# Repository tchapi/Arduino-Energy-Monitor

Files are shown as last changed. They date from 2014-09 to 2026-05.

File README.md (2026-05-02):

Arduino and Node.js Energy Monitor
======================

Related blog post: https://tchap.me/blog/creating-a-simple-energy-monitor/

A little box that monitors the mains current and average room temperature and sends the data through WiFi to a server for storage, display and analysis.

Uses a **TMP36 temperature sensor** (like [this](https://www.sparkfun.com/products/10988)) and a **non-invasive current sensor** (like [this one](https://www.sparkfun.com/products/11005)), coupled with a **Wifi Shield** (this [one here](https://learn.adafruit.com/adafruit-cc3000-wifi)).

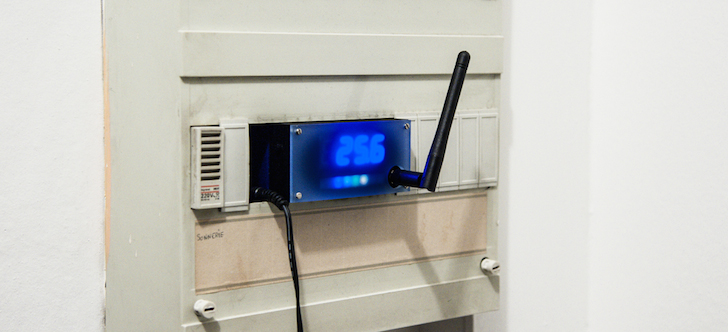
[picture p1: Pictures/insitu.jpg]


The box is the same size as a conventional NF EN 60898-1, and NFC 61-410 compliant circuit breaker, so it fits in your electrical panel.

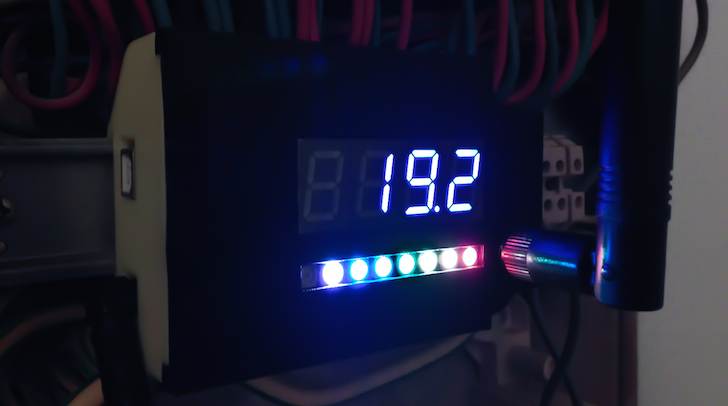
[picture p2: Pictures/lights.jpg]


## Code

The repo contains : 

  - the Arduino UNO code
  - A little Node.js server to receive the data

### Arduino code

The Arduino code is separated in different files, for ease of comprehension.

  - `CentralCurrentAndTempLogger.ino` is just here so the Arduino IDE is happy
  - `helpers.ino` define a general set of helper functions, like `readVcc()`
  - `display.ino` contains all the initialization processes for the 7-segment and the led strip
  - `wifi.ino` contains all the functions to work with WiFi
  - `current.ino` has all we need to compute current and temperature sensors
  - `main.ino` and `setup.ino` are self-explanatory.

> NB : these files are prefixed so that the compiler knows in which order to process them. This is required because in the Arduino IDE, there is no general file that imports every single file, so in order to define the compilation order, we need to rely on the filenames.

The configuration is stored in `config.h`. You need to copy `config.h.dist` to `config.h` and put your own settings (wifi, key) in there.

If you want to change the payload, you might want to look at lines `66`to `72` in `wifi.ino` :

```C
    client.print(encodedLength(str_temp) + encodedLength(str_power) + encodedLength(private_key) + 10);
    client.fastrprint(F("\r\n\r\nt="));
    urlEncode(client, str_temp, false, false);
    client.fastrprint(F("&w="));
    urlEncode(client, str_power, false, false);
    client.fastrprint(F("&key="));
    urlEncode(client, private_key, false, false);
```

> NB : it is advised to compile and upload the code with the Arduino IDE 1.0.5 version that can be found [here](http://www.arduino.cc/en/Main/OldSoftwareReleases#1.0.x) because the CC3000 shield is not really a big fan of the newer IDE releases.

### Server code

Of course, the server can be any application that can accept and process requests such as :

    POST 1.0 /data  key=123456789ABCD&w=346&t=23.5

The [Node.js](http://nodejs.org/) server provided is a very simple logger that stores the values in a file.

To launch the server, you first need to copy `config.json.dist` to `config.json` and put your own settings (log name, api path, key) in there.

Then, as for every standard Node.js app :

    node index.js

### About the `key` parameter

It's a very simple authentication system to prevent unwanted request to the server. Change for something only you know. The key must obviously be the same on the Arduino and on the server.

## Electronics

I created a custom PCB to hold the electronics (apart from the Arduino shield). It's designed on [Fritzing](http://fritzing.org/download/) which is a very practical tool.

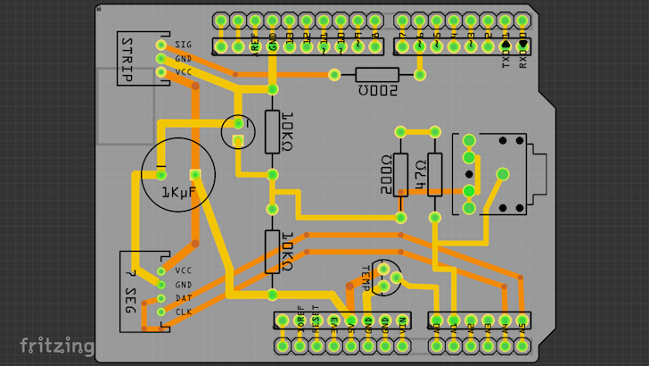
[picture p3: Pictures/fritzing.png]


The custom shield holds the connectors and some basic electronics. It is very simple to solder on your own.

BOM for the custom shield :

  - 1x 1000µF capacitor
  - 1x 10µF capacitor
  - 2x 10kΩ
  - 2x 200Ω
  - 1x 47Ω
  - 1x Stereo TRS connector (jack 3.5mm)
  - Some pin headers
  - 1x jst connector 3pin and x jst connector 4pin

To create the PCB, I use [Fritzing Fab](http://fab.fritzing.org/pricing) as well.

Other parts needed :

  - some wires
  - 1x Arduino UNO
  - 1x Adafruit CC3000 WiFi Shield
  - 1x antenna
  - 1x TMP36 temperature sensor
  - 1x non-invasive 30A current sensor
  - 1x Quad Alphanumeric Display - 0.54" Digits w/ I2C Backpack
  - 1x NeoPixel Stick - 8 x WS2812 5050 RGB LED with Integrated Drivers

## Casing

The casing consists of 3 _3D-printable_ parts :

  - the box in itself
  - the closing lid
  - the lid inset 

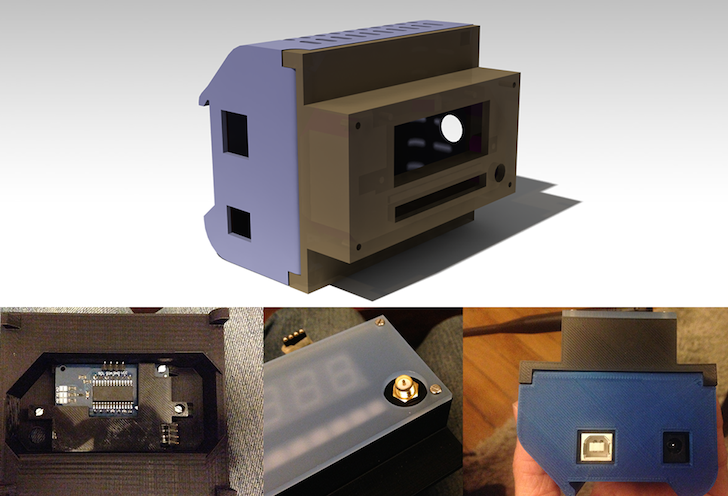
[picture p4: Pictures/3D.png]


All these parts are 3D printable on a regular **Rep Rap** or **Makerbot Replicator 2** for instance. The STL files (watertight, ready for print) are available in [the Design/Boîtier folder](https://github.com/tchapi/Arduino-Energy-Monitor/tree/master/Design/Bo%C3%AEtier%20principal/Exports%20STL).

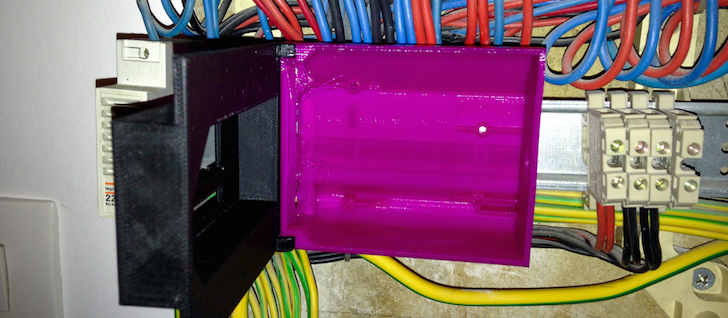
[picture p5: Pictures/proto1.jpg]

_A first prototype_

The CATIA files (.catpart and .catproduct) are available as well if you want to refactor them for your need.

To dim the displays and add a somehow nice touch to the objet, the fourth part is a little 3mm-thick plexiglass slap that can be cutted on a conventional laser cutter.

You can find the Illustrator file [here](https://github.com/tchapi/Arduino-Energy-Monitor/tree/master/Design/Bo%C3%AEtier%20principal/Plaque%20de%20protection%20plexiglas).

## Licence

Everything is released under the GNU GPL v2. Basically, you can reuse everything as long as you credit me somehow :)

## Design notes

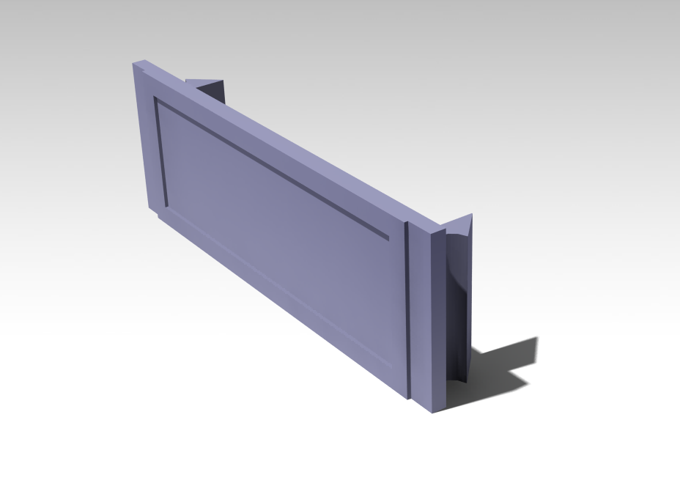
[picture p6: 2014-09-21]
Design/Obturateur pour tableau électrique/Obturateur1.png

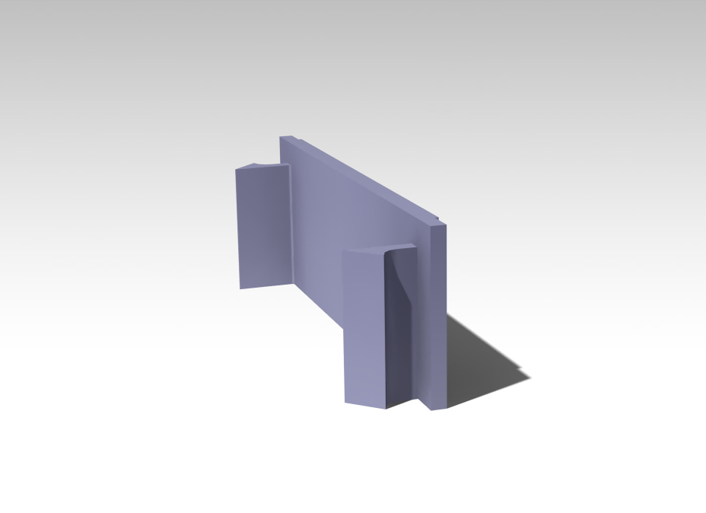
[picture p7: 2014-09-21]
Design/Obturateur pour tableau électrique/Obturateur2.png

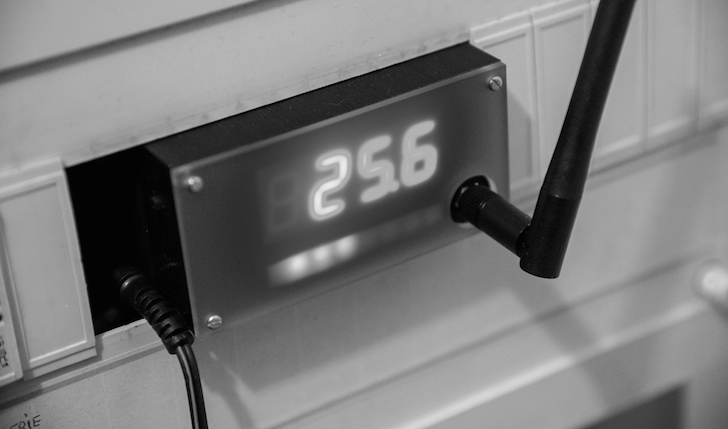
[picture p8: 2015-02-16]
Pictures/closeup.jpg

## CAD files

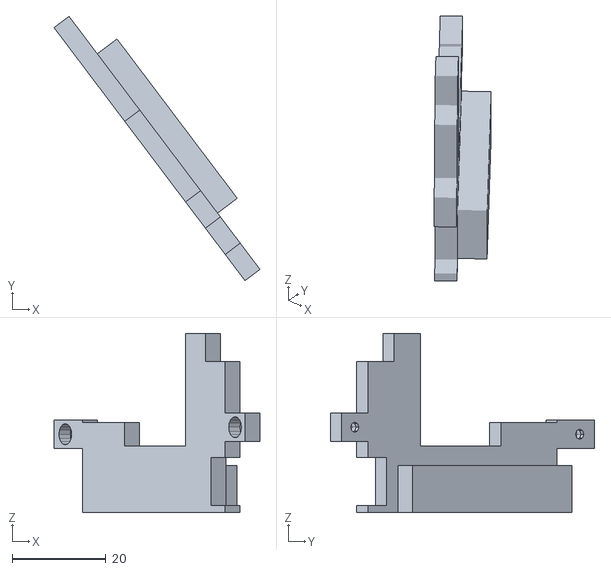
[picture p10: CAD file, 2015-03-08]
Design/Boîtier principal/Exports STL/plate_final.stl
43.9 x 56.3 x 38.2

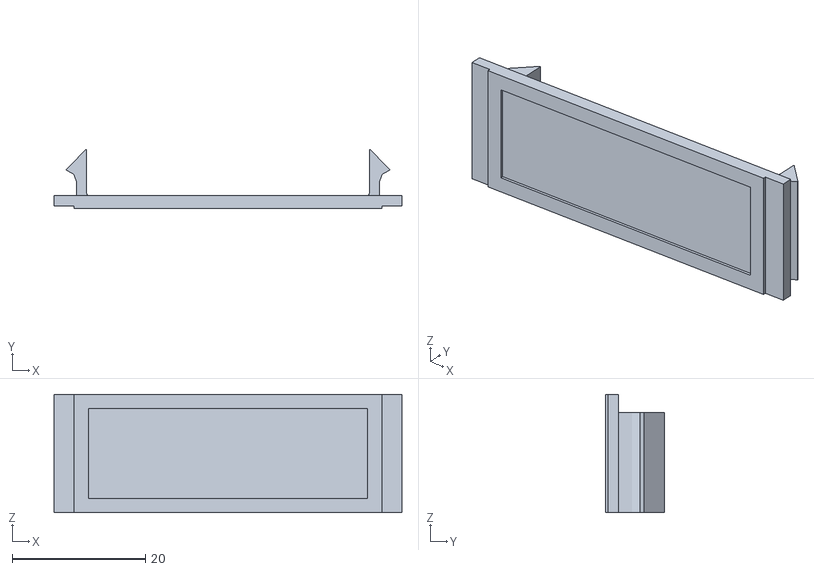
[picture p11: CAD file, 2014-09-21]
Design/Obturateur pour tableau électrique/Obturateur.stl
52.2 x 8.93 x 17.8

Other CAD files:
Design/Boîtier principal/Arduino UNO.CATPart
Design/Boîtier principal/Current & Temp Sensor.CATProduct
Design/Boîtier principal/Rail.CATPart
Design/Obturateur pour tableau électrique/Obturateur.CATPart

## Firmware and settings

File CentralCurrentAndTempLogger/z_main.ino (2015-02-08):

void loop() {

  /**************************************/
  /*              SAMPLING              */
  /**************************************/
  strip.setPixelColor(1,255,255,255);
  strip.show();

  double Irms = calcIrms(1480);  // Calculate Irms only
  int W = (int)(Irms*VOLTAGE);

  double temp = getTemperature(5000);  // Calculate T
// 
//  if (DEBUG) { 
//    Serial.print("Apparent Instant Power : ");
//    Serial.print(W);  // Apparent power
//    Serial.print(" W (");
//    Serial.print(Irms);  // Irms
//    Serial.println("A) ");
//
//    Serial.print("Apparent Temperature : ");
//    Serial.print(temp);  // Apparent temp
//    Serial.println("C");
//  }
  
  // Not sampling anymore
  strip.setPixelColor(1,0,0,0);
  strip.show();
  
  if (first_loop == false) { // On the first loop, we skip displaying
    
    /**************************************/
    /*          DISPLAYING POWER          */
    /**************************************/
    // We got 6 LEDS so let's compute the number that we need to lit
    if (W < 2) {
      nb_leds = 0;
    } else {
      nb_leds = ceil(W / (MAX_CURRENT * VOLTAGE) * 6); 
    }
    
    // lit them !
    for(int k=2;k<8; k++) {
      if (k<nb_leds + 2) {// + 2 since two leds are for wifi and sampling
        strip.setPixelColor(k,colors[k]);
      }  else {
        strip.setPixelColor(k,0,0,0);
      }
    }
    
    strip.show();
  
    /**************************************/
    /*          DISPLAYING TEMP           */
    /**************************************/
    
    matrix.clear(); // Clears just in case

    // Round up
    int temp_display = floor(temp*10);
    // 4 digit display
    matrix.writeDigitNum(1, (temp_display % 1000) / 100);
    matrix.writeDigitNum(3, (temp_display % 100) /10, true);
    matrix.writeDigitNum(4, temp_display % 10);
    
    // We need to call this to display changes in the matrix:
    matrix.writeDisplay();
  
    /**************************************/
    /*               SENDING              */
    /**************************************/

    // if ten seconds have passed since your last connection,
    // then connect again and send data:
    if (millis() - lastConnectionTime > postingInterval || millis() < lastConnectionTime /* millis() will overflow after 50days approx */) {
      strip.setPixelColor(0,255,255,255);
      strip.show();
      bool result = sendValues(temp, W); // Actually send to the server
    
      // Display a different color depending on the result
      strip.setPixelColor(0,(result == false)?red:green);
      strip.show();
      lastConnectionTime = millis();
      delay(250);
      
      if (result == false) {
        // Trying to reconnect
        strip.setPixelColor(0,orange);
        strip.show();
        setup_wifi();
        lastConnectionTime = millis();
      }
      
      // Led off
      strip.setPixelColor(0,0,0,0);
      strip.show();
    }

  } else {
    strip.setPixelColor(1,green);
    strip.show();
  }
  
  /* DELAY FOR SAMPLING */
  delay(samplingInterval);
  first_loop = false;

}

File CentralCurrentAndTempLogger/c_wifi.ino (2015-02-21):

#include <Adafruit_CC3000.h>
#include <ccspi.h>
#include <SPI.h>
#include <string.h>
#include "utility/debug.h"
#include "utility/socket.h"
#include "config.h"

// These are the interrupt and control pins
#define ADAFRUIT_CC3000_IRQ   3  // MUST be an interrupt pin!
// These can be any two pins
#define ADAFRUIT_CC3000_VBAT  5
#define ADAFRUIT_CC3000_CS    10
// Use hardware SPI for the remaining pins
// On an UNO, SCK = 13, MISO = 12, and MOSI = 11
Adafruit_CC3000 cc3000 = Adafruit_CC3000(ADAFRUIT_CC3000_CS, ADAFRUIT_CC3000_IRQ, ADAFRUIT_CC3000_VBAT,
SPI_CLOCK_DIVIDER); // you can change this clock speed but DI

// Security can be WLAN_SEC_UNSEC, WLAN_SEC_WEP, WLAN_SEC_WPA or WLAN_SEC_WPA2
#define WLAN_SECURITY   WLAN_SEC_WPA2

// Wifi definitions
const unsigned long
    dhcpTimeout     = 30L * 1000L, // Max time to wait for address from DHCP
    connectTimeout  = 20L * 1000L, // Max time to wait for server connection
    responseTimeout = 2L * 1000L, // Max time to wait for data from server
    postingInterval = 3L * 1000L;  // Delay between posting data
unsigned long
    currentTime = 0L,
    lastConnectionTime = 0L;
Adafruit_CC3000_Client
  client;        // For WiFi connections
uint32_t ip = 0L, t;
char Wstr[15];
bool has_to_reconnect = false;

/* 

Send a value to a server

*/
bool sendValues(double temp, int W) {
  
  // Connect to numeric IP
  client = cc3000.connectTCP(ip, 80);

  if(client.connected()) { // Success!
    
    // Creating the message for POST
    char message[30 + 1] = "";
    char str_temp[4 + 1] = "";
    char str_power[5 + 1] = "";
    dtostrf(temp, 4, 1, str_temp);
    sprintf(str_power, "%d", W);
  
    debug(F("Sending POST data... "));
    
    client.fastrprint(F("POST "));
    client.fastrprint(endpoint);
    client.fastrprint(F(" HTTP/1.1\r\n"));
    client.fastrprint(F("Host: "));
    client.fastrprint(host);
    client.fastrprint(F("\r\nConnection: close\r\n"
                       "Content-Type: application/x-www-form-urlencoded;charset=UTF-8\r\n"
                       "Content-Length: "));
    client.print(encodedLength(str_temp) + encodedLength(str_power) + encodedLength(private_key) + 10);
    client.fastrprint(F("\r\n\r\nt="));
    urlEncode(client, str_temp, false, false);
    client.fastrprint(F("&w="));
    urlEncode(client, str_power, false, false);
    client.fastrprint(F("&key="));
    urlEncode(client, private_key, false, false);

    // Serial.print(F("OK\r\nAwaiting response..."));
    int c = 0;
    // Dirty trick: instead of parsing results, just look for opening
    // curly brace indicating the start of a successful JSON response.
    while(((c = timedRead()) > 0) && (c != '{'));
    if(c == '{') {
      debug(F("done."));
    } else if(c < 0) {
      matrix.print(0xEEEE, HEX);
      matrix.writeDisplay();
      debug(F("timeout."));
    } else {
      matrix.print(0xEBAD, HEX);
      matrix.writeDisplay();
      debug(F("error."));
    }
    client.close();
    return (c == '{');
  } else {
    client.close();
    matrix.print(0xFAC0, HEX);
    matrix.writeDisplay();
    debug(F("Failed to connect."));
    return false;
  }

}


// Read from client stream with a 5 second timeout.  Although an
// essentially identical method already exists in the Stream() class,
// it's declared private there...so this is a local copy.
int timedRead(void) {
  unsigned long start = millis();
  while((!client.available()) && ((millis() - start) < responseTimeout));
  return client.read();  // -1 on timeout
}

/*

Minimalist time server query; adapted from Adafruit Gutenbird sketch,
which in turn has roots in Arduino UdpNTPClient tutorial.

*/
/*
unsigned long getTime(void) {

  uint8_t       buf[48];
  unsigned long ip, startTime, t = 0L;

 debug(F("Locating time server..."));

  // Hostname to IP lookup; use NTP pool (rotates through servers)
  if(cc3000.getHostByName("pool.ntp.org", &ip)) {
    static const char PROGMEM
      timeReqA[] = { 227,  0,  6, 236 },
      timeReqB[] = {  49, 78, 49,  52 };

    debug(F("found\r\nConnecting to time server..."));
    startTime = millis();
    do {
      client = cc3000.connectUDP(ip, 123);
    } while((!client.connected()) &&
            ((millis() - startTime) < connectTimeout));

    if(client.connected()) {
      debug(F("connected!\r\nIssuing request..."));

      // Assemble and issue request packet
      memset(buf, 0, sizeof(buf));
      memcpy_P( buf    , timeReqA, sizeof(timeReqA));
      memcpy_P(&buf[12], timeReqB, sizeof(timeReqB));
      client.write(buf, sizeof(buf));

      debug(F("OK\r\nAwaiting response..."));
      memset(buf, 0, sizeof(buf));
      startTime = millis();
      while((!client.available()) &&
            ((millis() - startTime) < responseTimeout));
      if(client.available()) {
        client.read(buf, sizeof(buf));
        t = (((unsigned long)buf[40] << 24) |
             ((unsigned long)buf[41] << 16) |
             ((unsigned long)buf[42] <<  8) |
              (unsigned long)buf[43]) - 2208988800UL;
       debug(F("success!"));
      }
      client.close();
    }
  }
  if(!t) debug(F("error"));
  return t;
}
*/
// For URL-encoding functions below
static const char PROGMEM hexChar[] = "0123456789ABCDEF";

// URL-encoding output function for Print class.
// Input from RAM or PROGMEM (flash).  Double-encoding is a weird special
// case for Oauth (encoded strings get encoded a second time).
void urlEncode(
  Print      &p,       // EthernetClient, Sha1, etc.
  const char *src,     // String to be encoded
  boolean     progmem, // If true, string is in PROGMEM (else RAM)
  boolean     x2)      // If true, "double encode" parenthesis
{
  uint8_t c;

  while((c = (progmem ? pgm_read_byte(src) : *src))) {
    if(((c >= 'a') && (c <= 'z')) || ((c >= 'A') && (c <= 'Z')) ||
       ((c >= '0') && (c <= '9')) || strchr_P(PSTR("-_.~"), c)) {
      p.write(c);
    } else {
      if(x2) p.print("%25");
      else   p.write('%');
      p.write(pgm_read_byte(&hexChar[c >> 4]));
      p.write(pgm_read_byte(&hexChar[c & 15]));
    }
    src++;
  }
}

// Returns would-be length of encoded string, without actually encoding
int encodedLength(char *src) {
  uint8_t c;
  int     len = 0;

  while((c = *src++)) {
    len += (((c >= 'a') && (c <= 'z')) || ((c >= 'A') && (c <= 'Z')) ||
            ((c >= '0') && (c <= '9')) || strchr_P(PSTR("-_.~"), c)) ? 1 : 3;
  }

  return len;
}

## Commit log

2014-10-23 Add PCB (Fritzing board)
    [Board.fzz]
2014-10-30 Modify PCB for A4 and A5 Improve Arduino sketch
    [Board.fzz]
2014-10-30 More board improvements
    [Board.fzz]
2015-01-12 Correct Wifi implementation Reduce code size (comments) Fixups
    [b_wifi.ino, d_current.ino, z_main.ino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]
2015-01-19 Add a little node server for the backend part Correct the POST sending routine
    [b_wifi.ino]
2015-01-19 Correct char vs. const char
    [b_wifi.ino]
2015-02-07 Display should be initialized before wifi to show errors More error displaying with the screen, as error codes Small improvements Introducing a temperature bias for real world data
    [b_display.ino, c_wifi.ino, d_current.ino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]
2015-02-14 Remove correction for now, now uses TMP36
    [d_current.ino]
2015-02-15 Add design files : CATIA, STL, Laser cutted
    [Arduino UNO.CATPart, Current & Temp Sensor.CATProduct, Rail.CATPart]
2015-02-15 Current is now in config
2015-02-17 Longer timeouts and add a reset function
    [a_helpers.ino, c_wifi.ino, z_setup.ino]
2015-02-21 Stop hanging on error and resetFunc instead
    [a_helpers.ino, c_wifi.ino, z_setup.ino]
2015-03-08 New design versions
    [Arduino UNO.CATPart, Current & Temp Sensor.CATProduct, Rail.CATPart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]
2015-05-22 Use a different method for resetting Use the timer in the ATMega328P
    [a_helpers.ino, z_setup.ino]
